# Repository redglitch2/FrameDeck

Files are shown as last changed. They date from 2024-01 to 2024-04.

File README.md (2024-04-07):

# FrameDeck
The First Open Source Framework Powered Handheld

## Components:
- **Motherboard**: [Framework 13 Mainboard](https://frame.work/ca/en/products/mainboard-11th-gen-intel-core?v=FRANFG000B)
- **Screen**: [7 inch 1200p Display+Digitizer](https://www.aliexpress.com/item/1005004436708817.html?spm=a2g0o.order_list.order_list_main.4.4edf1802nBw2VC)
- **battery**: [Framework Battery](https://frame.work/ca/en/products/battery?v=FRANBBAT01)
- **Wifi Card**:[Wifi 6](https://frame.work/ca/en/products/intel-wi-fi-6-ax201-vpro)
- **Ram**:[16gb SODIMM DDR4 Ram](https://frame.work/ca/en/products/ram?v=P2008X2)
- **SSD**:[M.2 NVME SSD](https://frame.work/ca/en/products/wd_black-sn730-nvme?v=FRANRVWD02)
- **Speakers**:[Speakers](https://frame.work/ca/en/products/speaker-kit?v=FRANBXFG03)
- **HDMI Ribbon Cable**:[Cable](https://www.aliexpress.com/item/1005002200767476.html?spm=a2g0o.order_list.order_list_main.51.4edf1802nYUJw7)
- **180 Degree USB-C**: [USB-C Cable](https://www.aliexpress.com/item/1005004456693859.html?spm=a2g0o.order_list.order_list_main.71.4edf1802nYUJw7)
- **Philips Screw Kit**: [Screws](https://www.aliexpress.com/item/4001010449485.html?spm=a2g0o.order_list.order_list_main.91.4edf1802nYUJw7)
- **Joysticks**: [10K Joysticks](https://www.aliexpress.com/item/1005004705173404.html?spm=a2g0o.order_list.order_list_main.121.4edf1802nYUJw7)
- **Potentiometer**: [Potentiometer For Triggers](https://www.aliexpress.com/item/1005004351096449.html?spm=a2g0o.order_list.order_list_main.161.4edf1802nYUJw7)
- **Face Buttons**: [Kalih Choc Switches For Face Buttons](https://www.aliexpress.com/item/4000803757746.html?spm=a2g0o.order_list.order_list_main.171.4edf1802nYUJw7)
- **Hotswap Socket**: [Hotswap Socket for Kalih Switches](https://www.aliexpress.com/item/4000803757746.html?spm=a2g0o.order_list.order_list_main.171.4edf1802nYUJw7)
- **90 Degree USB-C**: [USB-C Cable](https://www.aliexpress.com/item/1005003275834471.html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)
- **Joystick Cover**: [Cover](https://www.aliexpress.com/item/4000703242542.html?spm=a2g0o.order_list.order_list_main.76.4edf1802nYUJw7)
- **Torsion Spring**: [Spring For Trigger Assembly](https://www.aliexpress.com/item/1005005282110460.html?spm=a2g0o.order_list.order_list_main.81.4edf1802nYUJw7)
- **Thunderbolt Extension**:[Tb3 Extension Cable](https://www.aliexpress.com/item/1005003781125271.html?spm=a2g0o.order_list.order_list_main.176.4edf1802nYUJw7)
- **Buttons**:[Start/Select Buttons](https://www.aliexpress.com/item/1005004073358461.html?spm=a2g0o.order_list.order_list_main.273.4edf1802nYUJw7)
- **USB-C Arduino Pro Micro**: [Arduino For Controller](https://www.aliexpress.com/item/32887074671.html?spm=a2g0o.order_list.order_list_main.278.4edf1802nYUJw7)
- **USB-C to HDMI Adaptr***:[HDMI Adapter](https://www.aliexpress.com/item/4000617378200.html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)

## 3D Printed Parts:
- Revision 1 Out - January 26, 2024
  
## PCBs:
- Revision 1 Out - January 26, 2024

## Videos:
- Part 1: [Out Now](https://youtu.be/XlbybcZxy6A)
- Part 2: [Out Now](https://www.youtube.com/watch?v=zO6Jn7tTwc8)

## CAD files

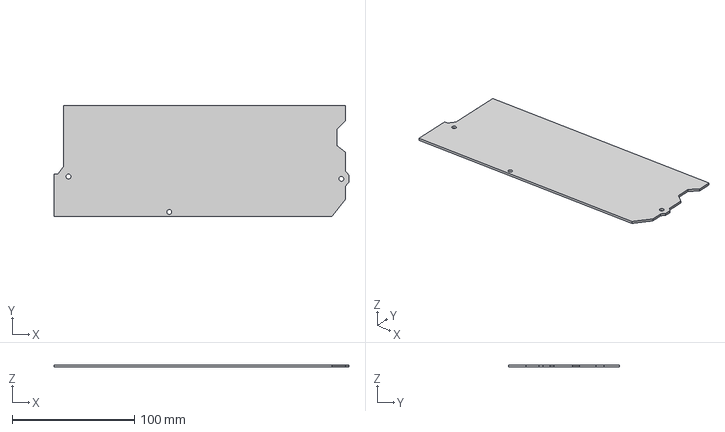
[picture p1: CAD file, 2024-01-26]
Step Files Rev.1/Mainboard_Frame.step
241.5 x 91.0 x 2.00 mm

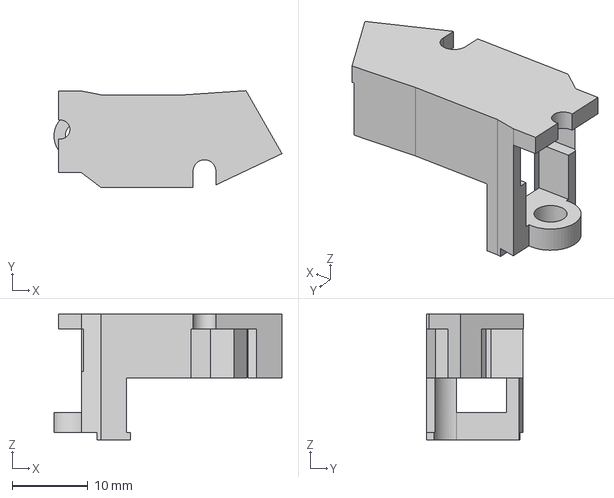
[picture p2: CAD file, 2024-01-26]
Step Files Rev.1/Trigger_Shoulder_Assembly_Left.step
30.1 x 12.8 x 16.6 mm

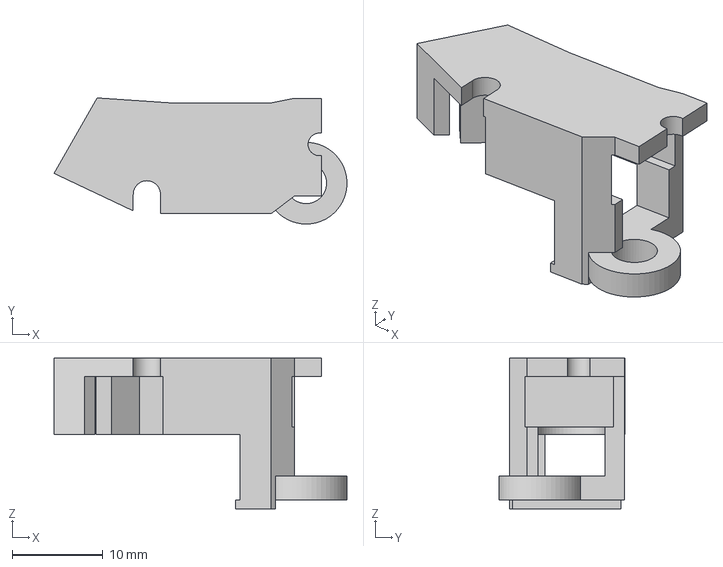
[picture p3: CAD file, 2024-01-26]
Step Files Rev.1/Trigger_Shoulder_Assembly_Right.step
32.3 x 13.9 x 16.6 mm

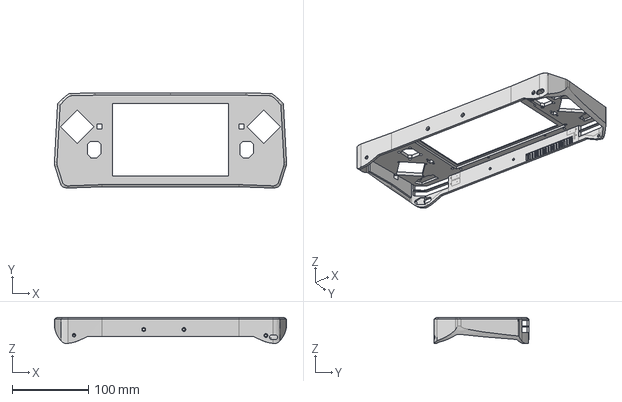
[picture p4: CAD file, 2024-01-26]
Step Files Rev.1/Main_Chassis.step
303.9 x 124.6 x 34.1 mm

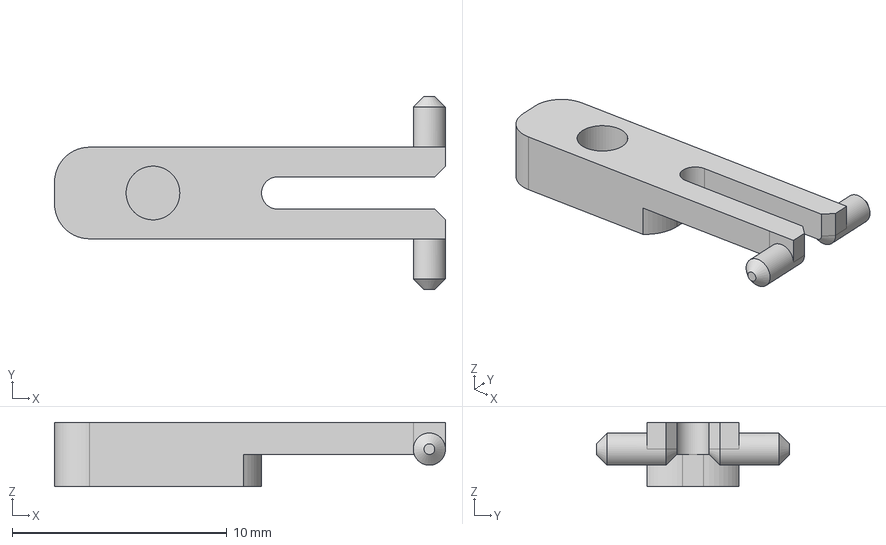
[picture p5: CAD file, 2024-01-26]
Step Files Rev.1/Power_Button.step
18.2 x 9.00 x 3.00 mm

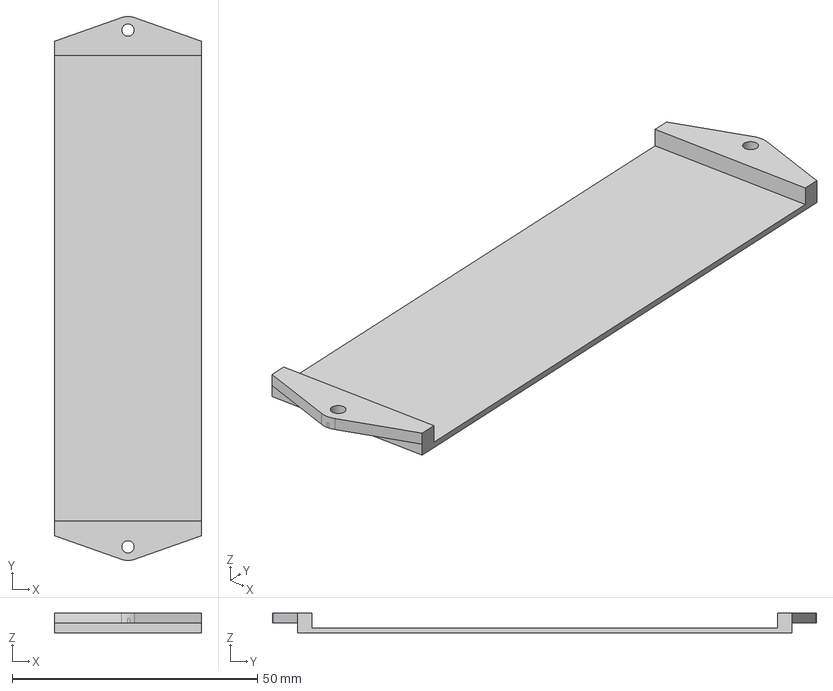
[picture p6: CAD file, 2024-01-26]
Step Files Rev.1/Screen_Brace_Left.step
30.0 x 111.0 x 4.00 mm

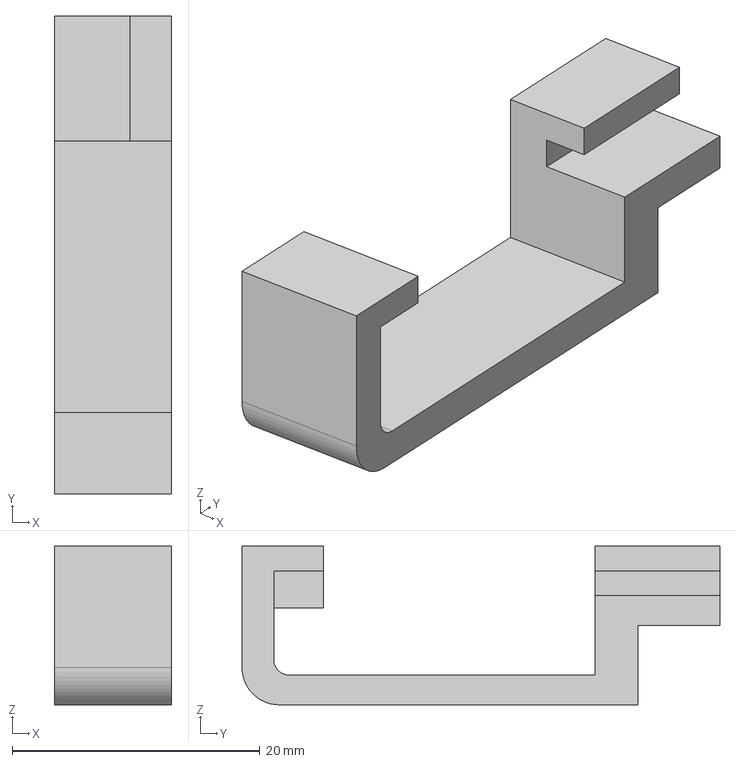
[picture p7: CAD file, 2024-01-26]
Step Files Rev.1/Wifi_Brace.step
9.46 x 38.6 x 12.8 mm

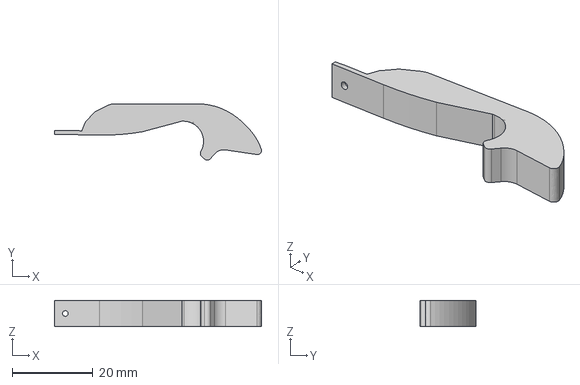
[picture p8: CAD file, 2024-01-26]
Step Files Rev.1/Trigger_Left.step
51.4 x 14.0 x 6.50 mm

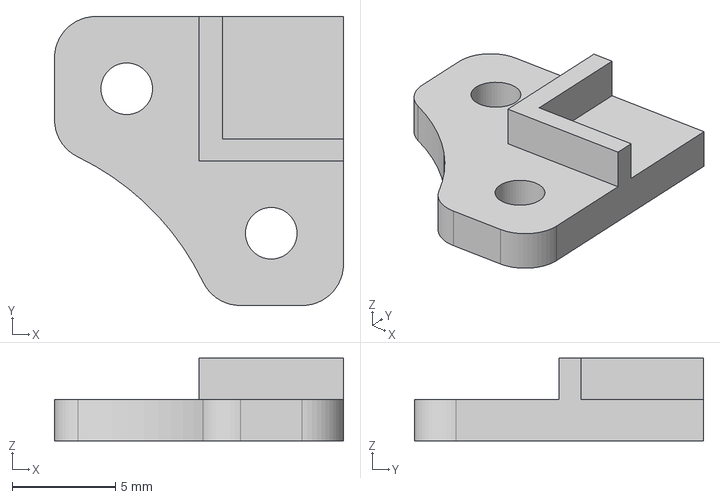
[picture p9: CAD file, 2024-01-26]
Step Files Rev.1/Screen_Frame_Bottom_Right.step
14.0 x 14.0 x 4.00 mm

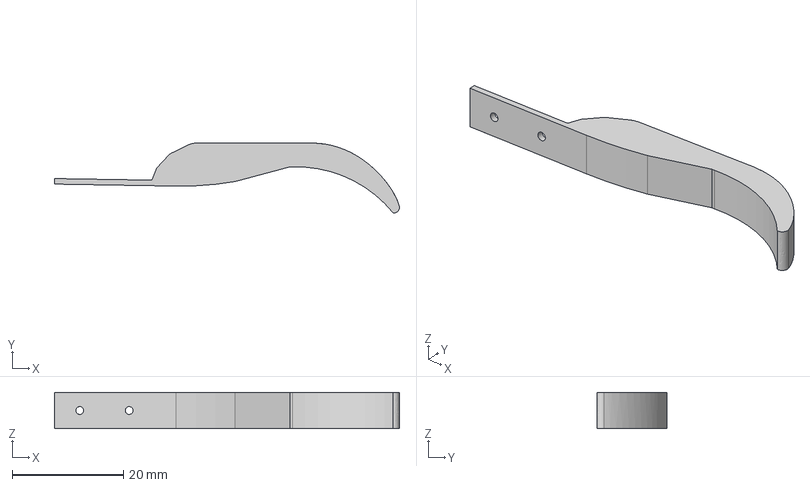
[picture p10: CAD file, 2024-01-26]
Step Files Rev.1/Shoulder_Left.step
62.1 x 12.6 x 6.50 mm

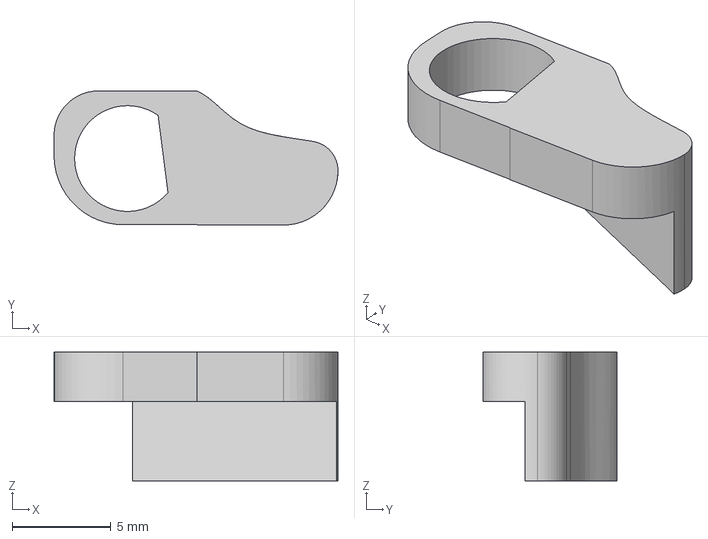
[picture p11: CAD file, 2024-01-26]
Step Files Rev.1/Pot_Arm_Left.step
14.4 x 6.78 x 6.50 mm

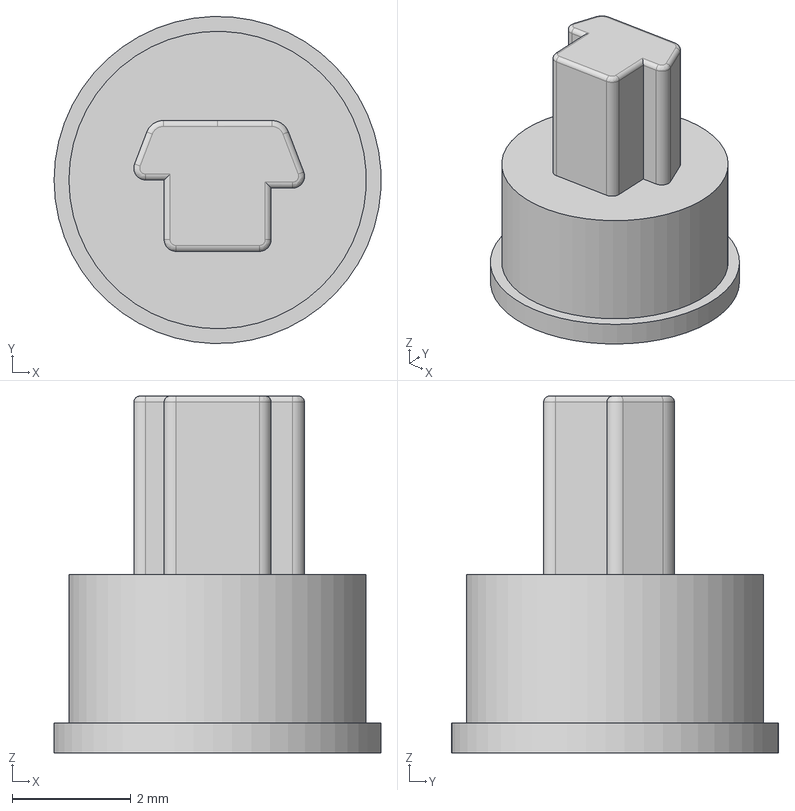
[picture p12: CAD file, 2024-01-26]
Step Files Rev.1/Poteniometer_Cap_1.step
5.50 x 5.50 x 6.00 mm

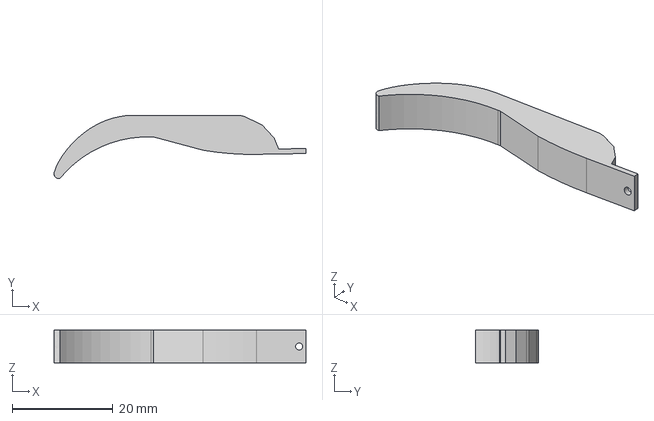
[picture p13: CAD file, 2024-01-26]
Step Files Rev.1/Trigger_Right.step
50.0 x 12.6 x 6.50 mm

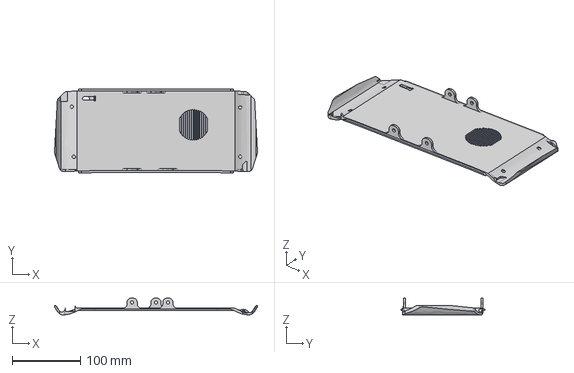
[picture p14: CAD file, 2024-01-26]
Step Files Rev.1/Back_Cover.step
298.1 x 123.7 x 24.9 mm

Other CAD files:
Step Files Rev.1/Screen_Frame_Top_Right.step
Step Files Rev.1/Screen_Frame_Bottom_Left.step
Step Files Rev.1/Screen_Frame_Top_Left.step
Step Files Rev.1/Start_Brace.step
Step Files Rev.1/Pot_Arm_Right.step
Step Files Rev.1/Screen_Brace_Right.step
Step Files Rev.1/Select_Brace.step
Step Files Rev.1/Thunderbolt_Brace_Bottom.step
Step Files Rev.1/Thunderbolt_Brace_Top.step

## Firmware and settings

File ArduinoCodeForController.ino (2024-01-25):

#include <Joystick.h>
Joystick_ Joystick(JOYSTICK_DEFAULT_REPORT_ID, JOYSTICK_TYPE_JOYSTICK,  12);
const int pins[12]={10,14,15,16,5,6,4,7,3,2,1,0};//UDLR ABXY select start ShoulderL,ShoulderR

void setup() {
  for(int i=0; i<sizeof(pins)/sizeof(pins[0]); i++) {
    pinMode(pins[i], INPUT_PULLUP);
  }
  pinMode(A0, INPUT);
  pinMode(A1, INPUT);
  pinMode(A2, INPUT);
  pinMode(A3, INPUT);
  pinMode(A8, INPUT);
  pinMode(A9, INPUT);
  Joystick.begin();
}

void loop() {
  //joystickRight
  Joystick.setXAxis(map(analogRead(A0), 0, 1023, 0, 255));
  Joystick.setYAxis(map(analogRead(A1), 0, 1023, 0, 255));
  //joystickLeft
  Joystick.setRxAxis(map(analogRead(A2), 1023, 0, 255, 0));
  Joystick.setRyAxis(map(analogRead(A3), 1023, 0, 255, 0));
  //Analog trigger left
  Joystick.setZAxis(map(analogRead(A8), 0, 1023, 255, 0));//values here should be diff
  //Analog trigger Right
  Joystick.setRzAxis(map(analogRead(A9), 0, 1023, 255, 0));//values here should be diff
  //digital buttons(all 12)
  for(int i=0; i<sizeof(pins)/sizeof(pins[0]); i++) {
    if(!digitalRead(pins[i])) {
      Joystick.pressButton(i);
    } else {
      Joystick.releaseButton(i);
    }
  }
  delay(10);
}
